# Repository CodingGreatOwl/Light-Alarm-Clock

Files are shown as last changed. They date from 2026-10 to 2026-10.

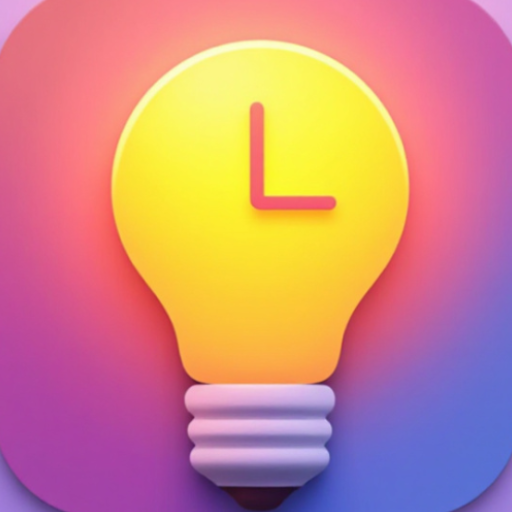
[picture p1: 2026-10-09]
Android/app/src/main/ic_launcher-playstore.png

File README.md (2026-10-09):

# LightAlarmClock

A hardware-software alarm clock system that combines an Android app, BLE communication, and an ESP32 firmware controller to trigger a pre-alarm light sequence before the alarm rings.

This project demonstrates end-to-end product engineering across mobile, embedded firmware, and electronics design.

## Why this project

Traditional alarms wake you up abruptly with sound. LightAlarmClock introduces a softer wake-up flow:

1. 10 minutes before alarm: Android app sends a BLE command
2. ESP32 receives command: firmware starts a timed IR/light transmission sequence
3. Alarm time: full alarm rings on phone with dismiss/snooze UI

This creates a practical blueprint for a smart alarm + ambient wake-up device.

## System Architecture

### 1) Android App (`Android/`)
- Built with Kotlin + Jetpack Compose
- Vibecoded Android implementation focused on fast iteration and feature validation
- Lets users:
  - create/edit/delete alarms
  - configure recurring schedules
  - choose ringtone
  - toggle vibration/notification
  - configure BLE target (device address, service UUID, characteristic UUID, message)
- Uses `AlarmManager.setExactAndAllowWhileIdle` for precise alarms
- Triggers a BLE foreground service (`BleMessageService`) 10 minutes before alarm
- Launches a full-screen alarm activity (`AlarmActivity`) and ringing service (`AlarmRingingService`) at alarm time

### 2) ESP32 Firmware (`Rust - ESP32/`)
- Built in Rust using `esp-idf-svc` + `esp32-nimble`
- Exposes a custom BLE service/characteristic
- On write, starts a state-machine-driven transmission (PWM + timer interrupts)
- Generates a modulated sequence (38.2 kHz carrier) suitable for IR/light control workflows

### 3) Hardware Shield (`LED_shield/`)
- KiCad project for custom LED/IR driver shield
- Includes:
  - schematic (`.kicad_sch`)
  - PCB layout (`.kicad_pcb`)
  - Gerber outputs (`GBR/`)
  - BOM (`BOM.csv`)
- Components include an IR LED (LD271), regulator (LM7805), and supporting passives/connectors

## Key Features

- End-to-end alarm pipeline from mobile UI to physical actuation
- Foreground services for reliable background BLE and alarm behavior
- Lock-screen alarm UX with Snooze / Dismiss actions
- Recurring alarm scheduling and day selection
- Hardware manufacturing assets included (Gerbers + BOM)

## Tech Stack

### Android
- Kotlin
- Jetpack Compose (Material 3)
- Android AlarmManager / BroadcastReceiver / Foreground Service

### Embedded
- Rust (edition 2021)
- `esp-idf-svc`
- `esp32-nimble` (BLE stack)

### Hardware
- KiCad (schematic + PCB)
- Through-hole + connector-based shield design

## Repository Structure

```text
LightAlarmClock/
├── Android/           # Kotlin Android app (UI, alarms, BLE client)
├── Rust - ESP32/      # ESP32 Rust firmware (BLE peripheral + signal generation)
├── LED_shield/        # KiCad hardware design + Gerbers + BOM
└── LICENSE            # GPL-3.0
```

## Getting Started

## Prerequisites

- Android Studio (latest stable)
- Android device running API 33+ (for current app config)
- ESP32 development board
- Rust + esp-idf toolchain for ESP32 builds
- BLE-capable phone and ESP32 in range

## 1) Run Android App

```bash
cd Android
./gradlew assembleDebug
```

Then install from Android Studio or via adb.

## 2) Flash ESP32 Firmware

From `Rust - ESP32/`, build/flash with your ESP-IDF Rust setup (tooling varies by environment).
The firmware advertises BLE service:

- Service UUID: `6827989e-079a-404f-946a-da39f968ce82`
- Characteristic UUID: `c696a5a1-827f-4df2-8260-5cdc7f0a4f44`

## 3) Configure BLE in App

In the app:
- Open Bluetooth Settings
- Enter ESP32 MAC address
- Confirm service/characteristic UUIDs
- Set message payload
- Use Test Connection and Send Test Message

## Alarm Flow (Runtime)

1. User schedules alarm in app
2. App registers:
   - main alarm trigger
   - BLE pre-alarm trigger (10 minutes earlier)
3. Pre-alarm fires -> `BlePreAlarmReceiver` starts `BleMessageService`
4. BLE write triggers ESP32 transmission sequence
5. Main alarm fires -> alarm UI + ringing foreground service
6. User snoozes or dismisses

## Recruiter Highlights

This project showcases:

- Cross-domain engineering: mobile + embedded + PCB
- Real-world Android architecture: alarms, receivers, services, lock-screen behavior
- Low-level firmware work: timers, PWM, BLE GATT handling
- System integration mindset: one product, multiple layers, clear signal path
- Product thinking: user-centric wake-up experience, not just a technical demo

## Known Improvements / Roadmap

- Add automated tests (unit + instrumentation) for alarm scheduling edge cases
- Improve BLE retry/backoff and connection lifecycle handling
- Add screenshots/GIFs for app UX in this README
- Add hardware bring-up and calibration guide
- Harden production alarm reliability across OEM battery optimizations

## License

This project is licensed under GNU GPL v3.0.
See [`LICENSE`](LICENSE).

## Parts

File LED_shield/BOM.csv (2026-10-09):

Reference | Value | Datasheet | Footprint | Qty | DNP
C1 | 0.33uF | ~ | Capacitor_THT:C_Rect_L7.0mm_W2.0mm_P5.00mm | 1
C2 | 0.1uF | ~ | Capacitor_THT:C_Rect_L7.0mm_W2.0mm_P5.00mm | 1
D1 | LD271 | http://www.alliedelec.com/m/d/40788c34903a719969df15f1fbea1056.pdf | LED_THT:LED_D5.0mm_IRGrey | 1
J1 | CON-left | ~ | Connector_PinSocket_2.54mm:PinSocket_1x10_P2.54mm_Vertical | 1
J2 | CON-Right | ~ | Connector_PinSocket_2.54mm:PinSocket_1x10_P2.54mm_Vertical | 1
J3,J4 | Screw_Terminal_01x02 | ~ |  | 2
R1 | 68 | ~ | Resistor_THT:R_Axial_DIN0411_L9.9mm_D3.6mm_P15.24mm_Horizontal | 1
U1 | LM7805_TO220 | https://www.onsemi.cn/PowerSolutions/document/MC7800-D.PDF | Package_TO_SOT_THT:TO-220-3_Vertical | 1

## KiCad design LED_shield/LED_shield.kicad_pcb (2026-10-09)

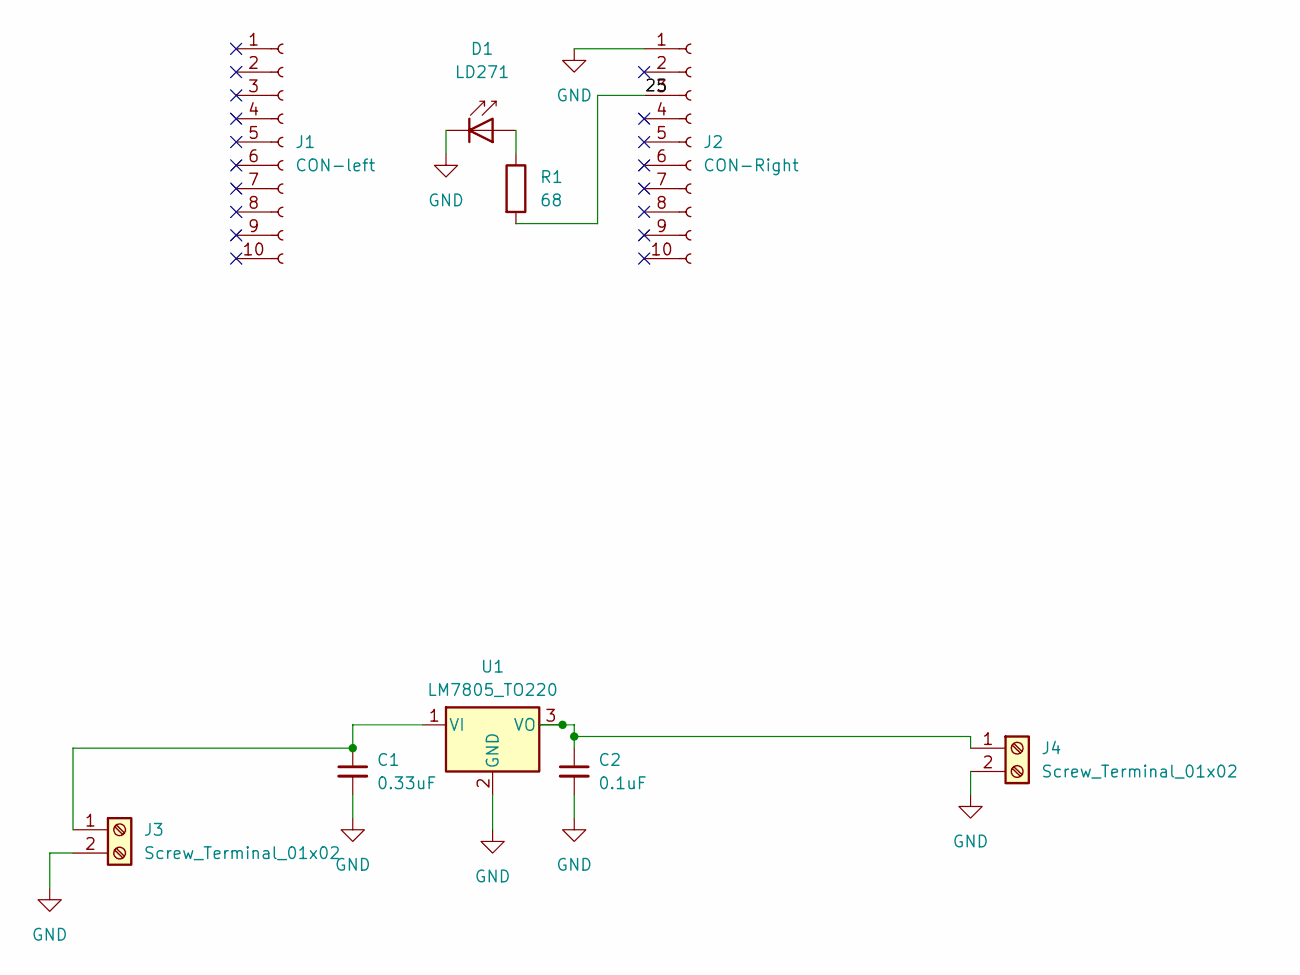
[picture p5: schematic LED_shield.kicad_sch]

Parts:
C1: 0.33uF; C_Rect_L7.0mm_W2.0mm_P5.00mm
C2: 0.1uF; C_Rect_L7.0mm_W2.0mm_P5.00mm
D1: LD271; LED_D5.0mm_IRGrey
J1: CON-left; PinSocket_1x10_P2.54mm_Vertical
J2: CON-Right; PinSocket_1x10_P2.54mm_Vertical
J3, J4: Screw_Terminal_01x02; TerminalBlock_MaiXu_MX126-5.0-02P_1x02_P5.00mm
R1: 68; R_Axial_DIN0411_L9.9mm_D3.6mm_P15.24mm_Horizontal
U1: LM7805_TO220; TO-220-3_Vertical

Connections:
/25: J2.3, R1.2
GND: C1.2, C2.2, D1.1 (K), J2.1, J3.2, J4.2, U1.2 (GND)
unnamed: D1.2 (A), R1.1
unnamed: C1.1, J3.1, U1.1 (VI)
unnamed: C2.1, J4.1, U1.3 (VO)

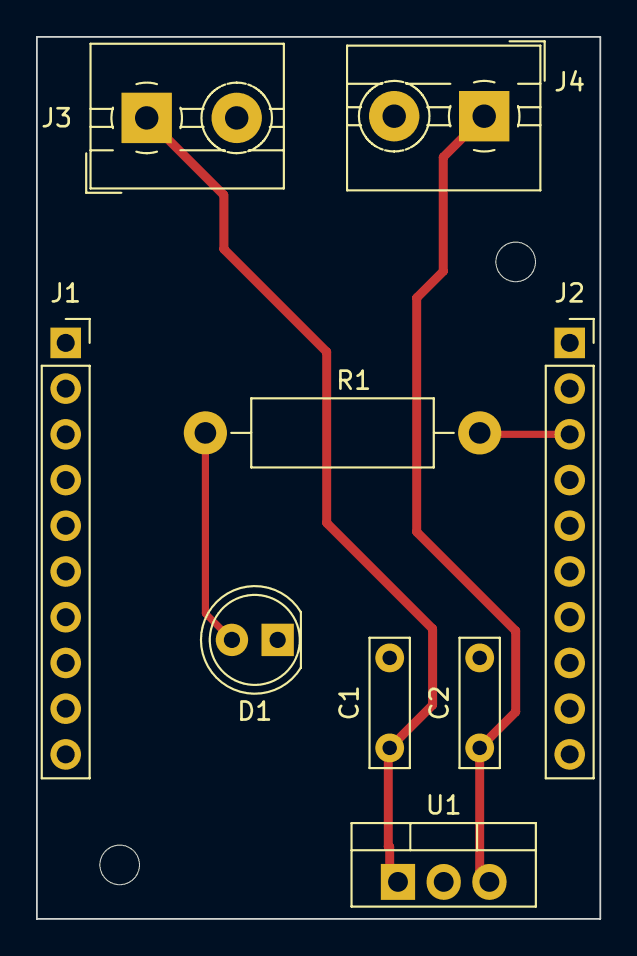
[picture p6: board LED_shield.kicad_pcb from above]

Board: 2 copper layers, 31.3 x 49.0 mm, 9 parts (0 on the bottom side), 5 nets.

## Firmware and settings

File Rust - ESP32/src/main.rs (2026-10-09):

use esp32_nimble::{uuid128, BLEAdvertisementData, BLEDevice, NimbleProperties};
use esp_idf_svc::hal::ledc::*;
use esp_idf_svc::hal::peripherals::Peripherals;
use esp_idf_svc::hal::prelude::*;
use std::num::NonZeroU32;
use esp_idf_svc::hal::task::notification::Notification;
use esp_idf_svc::hal::timer::TimerDriver;
use esp_idf_svc::hal::timer::config::Config;
use esp_idf_svc::hal::sys::EspError;

fn main() -> Result<(), EspError> {

    enum TransmissionState {
        Stop,
        Start,
        PauseLead,
        StartBit,
        EndBit,
        StopBurst,
    }

    const TimerLeadPulse:u64 = 3600;
    const TimerLeadPause:u64 = 1800;
    const TimerStartBit:u64 = 225; // 1 tick = 2.5 us
    const TimerPauseTransmission:u64 = 45000;
    const TimerEndBit0:u64 = 225;
    const TimerEndBit1:u64 = 675;
    const TimerEndTransmission:u64 = 40000;
    const TimerStopBurst:u64 = 225;

    let mut current_state = TransmissionState::Stop;

    esp_idf_svc::hal::sys::link_patches();

    let peripherals = Peripherals::take()?;

    // Configure the LED PWM
    let mut channel = LedcDriver::new(
        peripherals.ledc.channel0,
        LedcTimerDriver::new(
            peripherals.ledc.timer0,
            &config::TimerConfig::new().frequency(38200.Hz().into()),
        )?,
        peripherals.pins.gpio22, // gpio25
    )?;
    channel.set_duty(channel.get_max_duty() / 2)?;
    channel.disable()?;

    // Initialize timer for interupts
    let config = Config::new().auto_reload(true).divider(65000); // 200 // 65000 to make it debugable
    let mut timer = TimerDriver::new(peripherals.timer10, &config).unwrap();

    let tick_per_second = timer.tick_hz();
    timer.set_alarm(tick_per_second * 2)?;
    println!("Ticks per seconds : {tick_per_second}");

    let notification = Notification::new();
    let notifier = notification.notifier();

    let ble_notification = Notification::new();
    let ble_update = ble_notification.notifier();

    // Register the function to be called when timer interrupt is triggered.
    unsafe {
        timer.subscribe(move || {
            let bitset = 0b10001010101;
            notifier.notify_and_yield(NonZeroU32::new(bitset).unwrap());
        })?;
    }


    let mut is_next_bit_zero = true;
    let mut bits_to_transmit = 32;
    let mut finish = false;

    let command = 0xF7C03F;

    let mut value_changed:bool = false;
    let mut transmission_started = false;
    let device_name = "ESP32 Perif";
    esp_idf_svc::sys::link_patches();

    // Take ownership of device
    let ble_device = BLEDevice::take();

    // Obtain handle for peripheral advertiser
    let ble_advertiser = ble_device.get_advertising();

    // Obtain handle for server
    let server = ble_device.get_server();

    // Define server connect behaviour
    server.on_connect(|server, clntdesc| {
        // Print connected client data
        println!("{:?}", clntdesc);
        // Update connection parameters
        server
            .update_conn_params(clntdesc.conn_handle(), 24, 48, 0, 60)
            .unwrap();
    });

    // Define server disconnect behaviour
    server.on_disconnect(|_desc, _reason| {
        println!("Disconnected, back to advertising");
    });

    // Create a service with custom UUID
    let remoteControlLed = server.create_service(uuid128!("6827989e-079a-404f-946a-da39f968ce82"));

    // Create a characteristic to associate with created service
    let startSequence = remoteControlLed.lock().create_characteristic(
        uuid128!("c696a5a1-827f-4df2-8260-5cdc7f0a4f44"),
        NimbleProperties::WRITE | NimbleProperties::READ );

    // Modify characteristic value
    startSequence.lock().set_value(b"Start Value");

    startSequence.lock().on_write(move |write_args| {
        println!("Received: {}", String::from_utf8_lossy(write_args.recv_data()));
        unsafe {
        ble_update.notify_and_yield(NonZeroU32::new(0b1).unwrap());
        }
    });

    // Configure Advertiser Data
    ble_advertiser
        .lock()
        .set_data(
            BLEAdvertisementData::new()
                .name(device_name)
                .add_service_uuid(uuid128!("6827989e-079a-404f-946a-da39f968ce82")),
        )
        .unwrap();

    // Start Advertising
    ble_advertiser.lock().start().unwrap();

    // (Optional) Print dump of local GATT table
    // server.ble_gatts_show_local();


    // Enable the timer interruption
    timer.enable_interrupt()?;
    timer.enable_alarm(true)?;
    timer.enable(true)?;

    let mut command_repetion = 0;

    loop {

        if value_changed
        {
            timer.enable(true)?;
            transmission_started = true;
            value_changed = false;
            command_repetion = 3;
        }
        else if transmission_started {
            let bitset = notification.wait(esp_idf_svc::hal::delay::BLOCK);

            if let Some(bitset) = bitset {
                match current_state {
                    TransmissionState::Stop => {
                        current_state = TransmissionState::Start;
                        channel.enable()?;
                        timer.set_alarm(TimerLeadPulse)?;
                        bits_to_transmit = 32;
                        println!("Reached first interrupt");
                    },
                    TransmissionState::Start => {
                        current_state = TransmissionState::PauseLead;
                        channel.disable()?;
                        timer.set_alarm(TimerLeadPause)?;
                        println!("Reached second interrupt");
                    }
                    TransmissionState::PauseLead => {
                        current_state = TransmissionState::StartBit;
                        channel.enable()?;
                        timer.set_alarm(TimerStartBit)?;

                        is_next_bit_zero = ((1 << (bits_to_transmit - 1) ) & command) == 0;
                        println!("Reached third interrupt");
                    }
                    TransmissionState::StartBit => {
                        channel.disable()?;
                        if is_next_bit_zero {
                            timer.set_alarm(TimerEndBit0)?;
                        }
                        else {
                            timer.set_alarm(TimerEndBit1)?;
                        }
                        current_state = TransmissionState::EndBit;

                        bits_to_transmit = bits_to_transmit - 1;
                        finish = bits_to_transmit == 0;

                        if is_next_bit_zero {
                            println!("Transmit 0");
                        }
                        else {
                            println!("Transmit 1");
                        }
                    }
                    TransmissionState::EndBit => {
                        channel.enable()?;
                        if finish {
                            current_state = TransmissionState::StopBurst;
                            timer.set_alarm(TimerStopBurst)?;
                        }
                        else {
                            timer.set_alarm(TimerStartBit)?;
                            current_state = TransmissionState::StartBit;
                            is_next_bit_zero = ((1 << (bits_to_transmit - 1) ) & command) == 0;
                        }
                    }
                    TransmissionState::StopBurst => {
                        channel.disable()?;
                        current_state = TransmissionState::Stop;
                        if command_repetion > 0 {
                            command_repetion -= 1;
                            timer.set_alarm(TimerPauseTransmission)?;
                            println!("Waiting to repeat");
                        }
                        else {
                            timer.enable(false)?;
                            println!("Reached end transmission");
                            transmission_started = false;
                        }
                    }
                }
            }

        }
        else {
            println!("Let's wait for someone triggering the ble");
            let bitset = ble_notification.wait(esp_idf_svc::hal::delay::BLOCK);
            // Why does it triggers at the start ?
            println!("All right, let's start the transmission");
            value_changed = true;
        }

    }
}

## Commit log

2026-01-21 dismiss button in the notifications
2026-10-09 Add custom shield design
    [BOM.csv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]
2026-10-09 Add ESP32 code
